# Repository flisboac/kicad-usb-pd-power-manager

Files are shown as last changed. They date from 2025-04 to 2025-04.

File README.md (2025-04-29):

# USB-PD Power Manager

This is a USB-PD-capable Battery Charger and Power Path Module based on the [HUSB238 USB-PD Sink Controller](https://www.hynetek.com/uploadfiles/site/219/news/aabbbbdb-48c9-4a44-a6dc-2c15f53282e6.pdf) and [BQ25672 Battery Charger](https://www.ti.com/lit/ds/symlink/bq25672.pdf).

> This is **NOT** a finished project!

## Objectives

The main objective with this module is, quite literally, to make the "perfect Power Manager module/solution for any project." Obviously, "perfect" here is what I consider perfect myself, so here goes a laundry list of things I want from it:

1. Actually negotiate power when powered through USB, whatever the means.
    - A lot of projects just depend on the common 5.1K resistor on CC1/CC2 to get 5V/3A, but that's not a guarantee unless your use-case is very restricted.
    - Also, pulling 500mA or more on USB without USB connection/negotiation, USB-PD or USB-BC is out of spec. Not that it matters in all projects, but a well behaved USB-powered solution avoids many surprises.
    - 5V is pretty ubiquitous, but some projects may necessitate more voltage to drive higher-powered devices (e.g. fans), or to charge batteries more efficiently. Higher voltages are also necessary in order for USB-C to deliver more power in general.
2. Capable of negotiating power through **USB PD**, up to the highest power profile available (100W, 20V @ 5A).
    - In the future, I'd like this to be expanded to support USB-PPS as well, but chip availability is a bit low for enabling this functionality, so USB-PD will do for the moment.
3. Capable of falling back to **USB BC**, if not connecting to USB Type-C end-to-end.
    - There's plenty of power available through USB BC 1.2 or similar charger protocols, and it's still very common to use previous USB-A or USB-B (i.e. non Type-C) ports in many places.
4. Battery-powered, with a battery charger built-in.
    - Necessitates Power Path management.
    - Also necessitates battery protection measures, e.g. overcurrent protection, overvoltage protection, reverse polarity protection, etc.
5. Have the smallest possible form-factor. Be friendly to breadboarding, while still being useful as a standalone module.
    - Size would be similar to a Raspberry Pi Pico in width, but no specific restriction on length.
    - Ahem... ✨ [Castellations!](https://jlcpcb.com/blog/castellated-pcbs-introduction-and-design-requirements) ✨ (What a word, ain't it?)
6. Guaranteed 5V and 3.3V outputs, regardless of the "mains" voltage.
    - 5V with a switched dc/dc regulator, for powering sensors, LEDs, etc. Optionally adjustable to 3.3V via standalone (pin) configuration.
    - 3.3V with a LDO for powering microcontrollers, also adjustable to 5V if needed (e.g. for less noise).
    - Both can be disabled at any time, to reduce power consumption.
7. Optional external power input, as a backup for USB power.
8. Battery fuel gauge built-in to the module.
    - Helps with power consumption prediction, etc.
9. I2C as the main control option, but standalone pin or jumper based configuration also possible.
    - Standalone controls enable the board to be used in scenarios without a microcontroller.
    - I2C enables the board to be used with higher precision (e.g. negotiate USB-PD power after first negotiation, configure current/charger limits past the default standalone ones, monitor power consumption, etc.)

I also wanted to put a soft-reset button. I like the idea of the module having power and reset buttons that are useable to a microcontroller, with e.g. long presses meaning turn-off/reset, etc. Perhaps that may be included in a future revision.

## Implementation

### Component selection

Focus on ICs from known brands. Easier to predict availability and quality.

Basic test: go to JLCPCB and see if there's a good amount of stock available. Discard any option with zero stock. Price also important, but not essential (as this will be a personal project).

- USB-PD Sink Controller (**VUSB**): [**HUSB238_002DD**](https://www.hynetek.com/uploadfiles/site/219/news/aabbbbdb-48c9-4a44-a6dc-2c15f53282e6.pdf)
    - 001DD or 004DD would be the best option, but the 002DD has a whole lot more availability for some reason.
    - VUSB is not supposed to be consumed directly, but instead it must be passed on to the Power Path controller.
    - VUSB is only switched on when USB-PD negotiation is performed (either with success or failure).
- Battery Charger and Power Path (**VSYS**): [**BQ25672**](https://www.ti.com/lit/ds/symlink/bq25672.pdf)
    - Selected mostly because of the 24V input voltage tolerance.
    - Having I2C is also important, but not essential.
    - Could be the BQ25792 as well, it's pin-compatible and offers more power, but the BQ25672 has better availability
- Switch-mode DC/DC converter (**VSW**): [**TPS63070**](https://www.ti.com/lit/ds/symlink/tps63070.pdf)
    - Being able to step-up is important for scenarios with 1-cell batteries, or when the input voltage is lower than the output voltage in general. Even more important is to be able to step-down the voltage, considering the upwards of 24V inputs. Hence, it must be a buck-boost.
    - Input comes from VSYS (BQ25672), which reduces the required VIN to 19V.
    - Unfortunately, it has a 16V input voltage limit, but it's the highest limit amongst the moderately available buck-boosts out there. I found no other buck-boost as available or as cheap as this one. If anyone knows of a better option PLEASE let me know, I researched quite a lot but couldn't find a better one!
    - Because of the low VIN input, the module can only be used with up to 3-cell configurations, which limits VSYS to around 13V max. Going above that risks damaging the buck-boost.
- Low-dropout voltage regulator (**VLDO**): [**TPS7A2601**](https://www.ti.com/lit/ds/symlink/tps7a26.pdf)
    - I quite like this LDO!
    - Current limit is a bit low at 500mA, but it's enough for most projects. Higher power can be better served by VBUS or VSW
    - Target output voltages: 3.3V and 5V.
    - Has a very high VIN, at 20V. Safe to connect to VBUS/VSYS, but not exactly safe to use at higher voltages (e.g. regulate from 20V VIN but with much lower output currents in order not to blow it up!)
- MOSFETs: focus on using dual mosfet ICs, in order to reduce board space usage whenever possible.
    - Dual N-Channel: [**Si7224DN**](https://www.mouser.com/datasheet/2/427/si7224dn-1764912.pdf)
        - One of the channels has a lower Vgs, kinda weird. Could have chosen a better one.
    - Dual P-Channel: [**Si7223DN**](https://www.vishay.com/docs/75609/si7223dn.pdf)
    - N-channel and P-channel: [**DMC3025LDV**](https://www.diodes.com/datasheet/download/DMC3025LDV.pdf)
    - Focus on packages compatible with DFN-3x3. Small enough for higher power, whilst being easier to find replacements later on (e.g. chinese options like the HSBB3313, HSBB3909, HSBB6254, HSBB3202, etc.)
    - There were probably better options out there, but I got tired of looking at some point...
- Battery fuel gauge: [**MAX17205G**](https://www.analog.com/media/en/technical-documentation/data-sheets/max17201-max17215.pdf)
    - No particular reason for choosing this one other than the fact that it supports at least 3-cell batteries.
    - Has good performance, low power consumption and enough availability.
    - Useful that it can balance cells as well!

### Module topology

The KiCad schematic focuses on showing the whole module as a single page. I like the idea of being able to see the whole circuit at a glance, obviously separated by smaller logical parts, but this may not be optimal in order to show the constituent parts of the schematic as a whole.

So, follows below a diagram making more evident the constituent parts of the module, I hope it makes sense:

Topology

### Schematics

Schematics

[Schematics PDF here.](/docs/kicad/schematics/toy-usb-pd-power-manager.pdf)

### PCB layout

I stopped working on the PCB layout in order to re-evaluate the project and make a review in general, but all the constituent parts are laid out and routed (with some exceptions). For example, the switch-mode DC/DC converters are laid out according to datasheet suggestions, but are not connected to the overall board.

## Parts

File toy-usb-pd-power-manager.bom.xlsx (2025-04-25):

Id | Designator | Footprint | Order Quantity | Manufacturer Part Number | Supplier and ref
1 | Q11,Q10,Q8 | SOT-23 | 3 | AO3400A
2 | C28,C27,C25,C24,C23,C21,C19,C18,C17,C16,C15,C9 | C_0805_2012Metric | 12 | 22uF 35V
3 | C30,C26,C31,C22,C20,C11,C7,C6,C5 | C_0402_1005Metric | 9 | 100nF 35V
4 | C29,C8,C2 | C_0805_2012Metric | 3 | 10uF 35V
5 | C14,C13,C1 | C_0402_1005Metric | 3 | 47nF 35V
6 | C12,C10 | C_0402_1005Metric | 2 | 10pF 35V
7 | R57,R56,R50,R35 | R_0402_1005Metric | 4 | 56K Ohm
8 | R55 | R_0402_1005Metric | 1 | 51K Ohm
9 | R54 | R_0402_1005Metric | 1 | 68K Ohm
10 | R53 | R_0402_1005Metric | 1 | 1.5M Ohm
11 | R46,R29 | R_0402_1005Metric | 2 | 1.5K Ohm
12 | R45 | R_0402_1005Metric | 1 | 1K Ohm
13 | R44 | R_0402_1005Metric | 1 | 510 Ohm
14 | R43 | R_0402_1005Metric | 1 | 2.2K Ohm
15 | R42 | R_0402_1005Metric | 1 | 220K Ohm
16 | R41 | R_0402_1005Metric | 1 | 330K Ohm
17 | R40 | R_0402_1005Metric | 1 | 510K Ohm
18 | R39,R25,R23,R14,R12,R11,R10 | R_0402_1005Metric | 7 | 1M Ohm
19 | R38 | R_0402_1005Metric | 1 | 470K Ohm
20 | R28 | R_0402_1005Metric | 1 | 5.1K Ohm
21 | R27 | R_0402_1005Metric | 1 | 10K Ohm
22 | R26 | R_0402_1005Metric | 1 | 15K Ohm
23 | R24 | R_0402_1005Metric | 1 | 2M Ohm
24 | R22,R21,R20,R19 | R_0402_1005Metric | 4 | 4.7K Ohm
25 | R18,R17,R16,R15,R13,R9,R8,R7,R6 | R_0402_1005Metric | 9 | 10M Ohm
26 | R5 | R_0402_1005Metric | 1 | 100 Ohm
27 | R4 | R_0402_1005Metric | 1 | 10 Ohm
28 | R3,R2 | R_0402_1005Metric | 2 | 330 Ohm
29 | R1 | R_0402_1005Metric | 1 | 0 Ohm
30 | D15 | LED_0603_1608Metric | 1 | LED
31 | D14 | LED_0603_1608Metric | 1 | LED
32 | J4 | PinHeader_1x12_P2.54mm_Vertical | 2 | Pin Header 1x12 P2.54mm Vertical
33 | J3 | PinHeader_1x4_P2.54mm_Vertical | 1 | Pin Header 1x4 P2.54mm Vertical
34 | U4 | Texas_S-PWSON-N10_ThermalVias | 1 | TPS63060
35 | U3 | SPECIFIC_BQ25672RQMR | 1 | BQ25672
36 | U2 | SPECIFIC_TPS7A2601DRVR_NoThermalVias | 1 | TPS7A2601DRVR
37 | U1 | DFN-10-1EP_3x3mm_P0.5mm_EP1.7x2.5mm | 1 | HUSB238_002DD
39 | Q9,Q1 | Vishay_PowerPAK_1212-8_Dual | 2 | Si7223DN
40 | Q7,Q6,Q5 | SOT-363_SC-70-6 | 3 | BSS138PS
41 | Q4,Q3,Q2 | Vishay_PowerPAK_1212-8_Dual | 3 | Si7224DN
42 | L2,L1 | L_6.3x6.3_H3 | 2 | 1uH 8A
44 | D13,D12,D2,D1 | D_SOD-323 | 4 | 1N5819WS
45 | D11,D5,D4 | D_SMF | 3 | SMF24A
46 | D10 | D_SMA | 1 | 1SMA4747A
47 | D9,D6 | SOT-23-6 | 2 | SMF05CT1G
48 | D8,D7 | D_SMA | 2 | 1SMA4745A
49 | D3 | D_SOD-123F | 1 | SMF16CA
50 | C4,C3 | C_0805_2012Metric | 2 | 2.2uF 35V
52 | J1 | USB_C_Receptacle_GCT_USB4105-xx-A_16P_TopMnt_Horizontal | 1 | USB-C Receptacle GCT USB4105-xx-A 16P Top Mount Horizontal

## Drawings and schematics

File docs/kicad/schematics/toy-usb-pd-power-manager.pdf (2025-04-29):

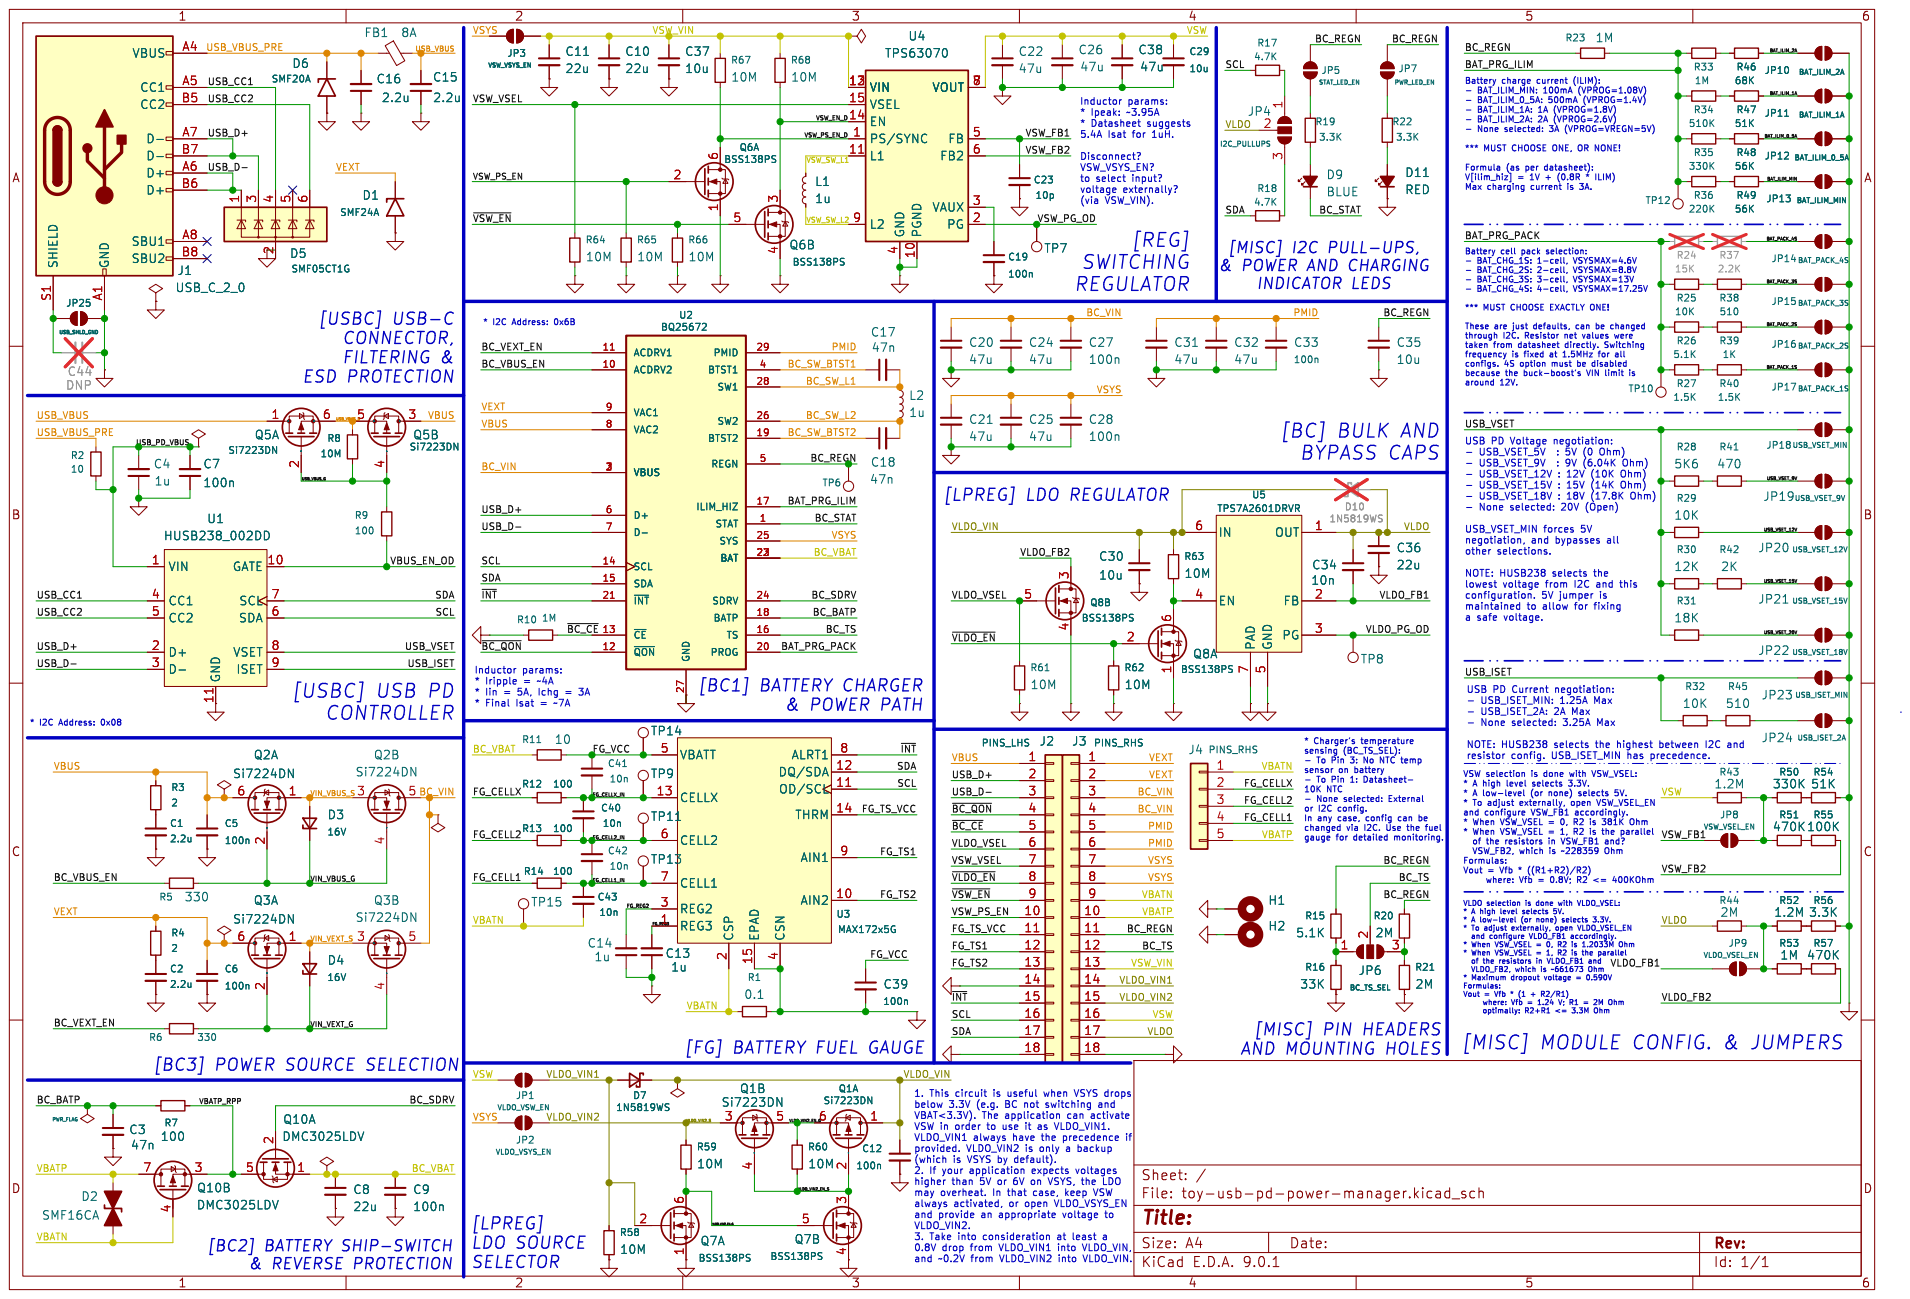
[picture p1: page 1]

6 1 U4 TPS63070 VIN 123 VSEL 15 EN 14 PS/SYNC 1

4 PGND 10 VOUT 78 FB 5 FB2 6 VAUX 3 PG 2 U4 TPS63070

4 PGND 10 VOUT 78 FB 5 FB2 6 VAUX 3 PG 2 C29
I2C_PULLUPS VIN 123 VSEL 15 EN 14 PS/SYNC 1

to select input voltage externally
(via VSW_VIN).
[REG]

a safe voltage. [LPREG] LDO REGULATOR

4 ALRT1 8 DQ/SDA 12 OD/SCL 11 THRM 14 AIN1 9 AIN2 10U3MAX172x5G H1 VIN 1 CC1 4 CC2 5 D+ 2 D- 3 GND 11 GATE 10 SCL 7 SDA 6 VSET 8

lowest voltage from I2C and this

VSW_FB1 USB_ISET
USB PD Current negotiation: - USB_ISET_MIN: 1.25A Max

4 ALRT1 8 DQ/SDA 12 OD/SCL 11 THRM 14 AIN1 9 AIN2 10

sensing (BC_TS_SEL): - To Pin 3: No NTC temp

sensor on battery
- To Pin 1: Datasheet- 10K NTC

[MISC] MODULE CONFIG. & JUMPERS

[FG] BATTERY FUEL GAUGE

Id: 1/1 Title: File: toy-usb-pd-power-manager.kicad_sch Sheet: /

0.8V drop from VLDO_VIN1 into VLDO_VIN, and ~0.2V from VLDO_VIN2 into VLDO_VIN. [LPREG]

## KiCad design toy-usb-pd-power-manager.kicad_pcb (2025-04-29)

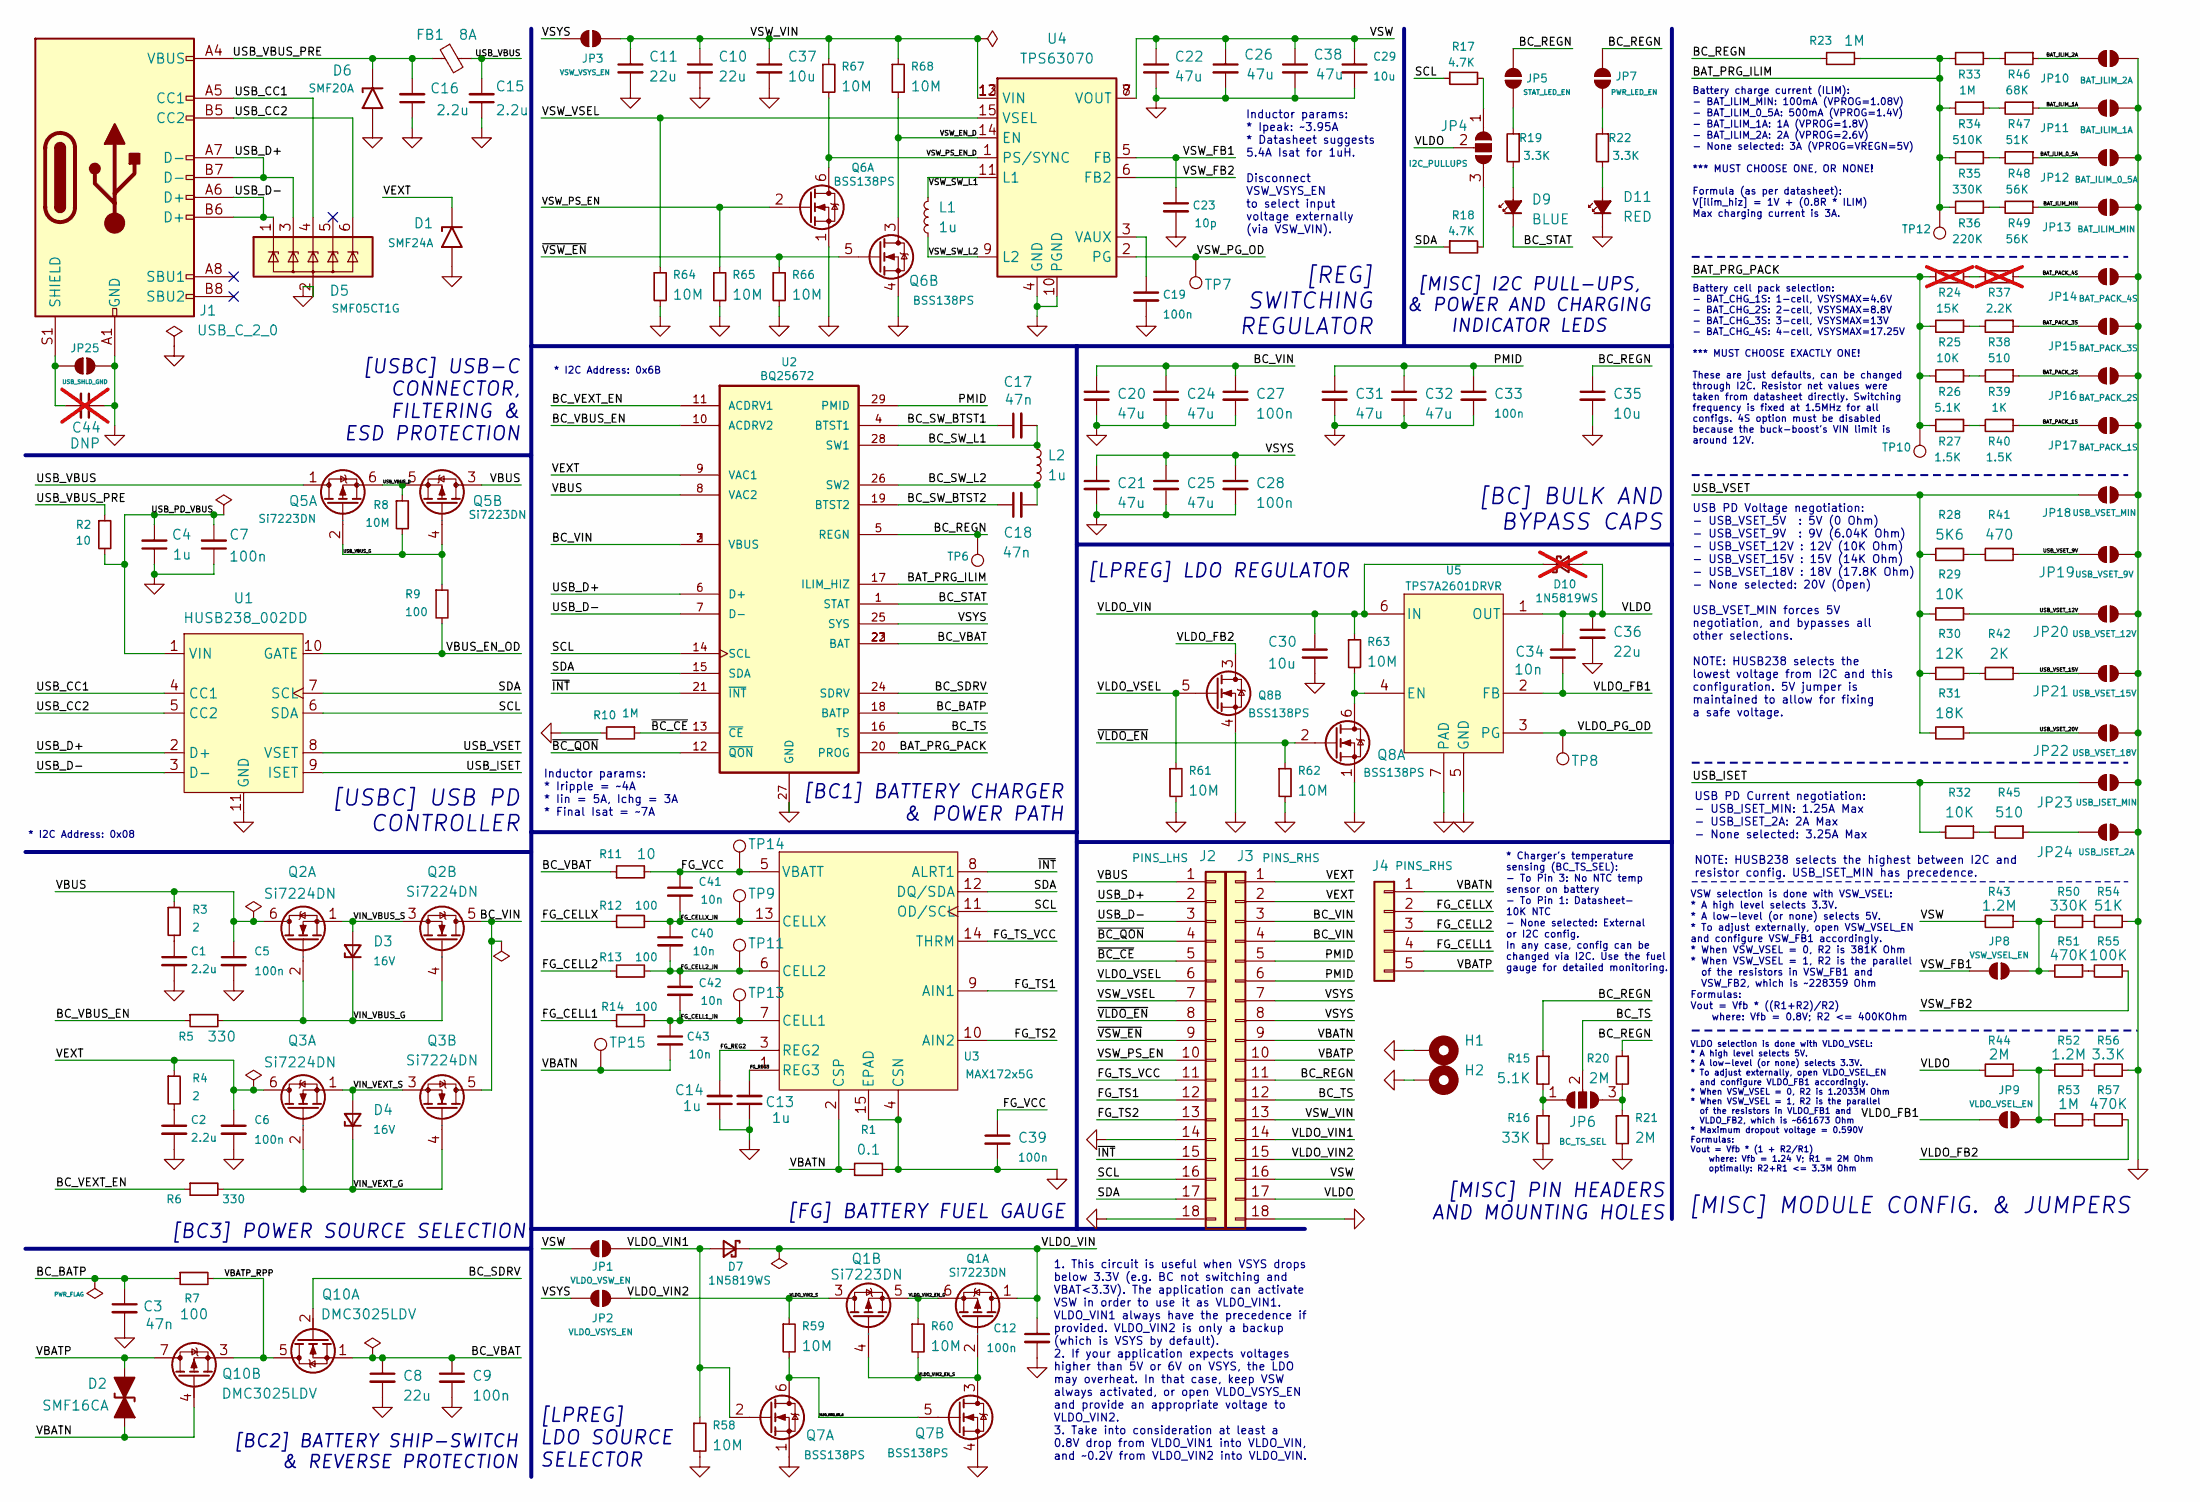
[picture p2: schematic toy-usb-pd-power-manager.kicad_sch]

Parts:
C1, C2: 2.2u; C_0805_2012Metric
C3, C17, C18: 47n; C_0402_1005Metric
C4, C13, C14: 1u; C_0402_1005Metric
C5, C6, C7, C9, C12, C19, C27, C28, C33, C39: 100n; C_0402_1005Metric
C8, C10, C11, C36: 22u; C_0805_2012Metric
C15, C16: 2.2u; C_0603_1608Metric
C20, C21, C22, C24, C25, C26, C31, C32, C38: 47u; C_0805_2012Metric
C23: 10p; C_0402_1005Metric
C29, C37: 10u; C_0603_1608Metric
C30, C35: 10u; C_0805_2012Metric
C34, C40, C41, C42, C43: 10n; C_0402_1005Metric
C44: DNP; C_0603_1608Metric; not fitted
D1: SMF24A; D_SMF
D2: SMF16CA; D_SOD-123F
D3, D4: 16V; D_SOD-523
D5: SMF05CT1G; SOT-23-6
D6: SMF20A; D_SMF
D7: 1N5819WS; D_SOD-323
D9: BLUE; LED_0603_1608Metric
D10: 1N5819WS; D_SOD-323; not fitted
D11: RED; LED_0603_1608Metric
FB1: 8A; L_1210_3225Metric
H1, H2: MountingHole_Pad; MountingHole_2.2mm_M2_DIN965_Pad_TopBottom
J1: USB_C_2_0; USB_C_Receptacle_GCT_USB4105-xx-A_16P_TopMnt_Horizontal
J2: PINS_LHS; PinHeader_1x18_P2.54mm_Vertical
J3: PINS_RHS; PinHeader_1x18_P2.54mm_Vertical
J4: PINS_RHS; PinHeader_1x05_P2.54mm_Vertical
JP1: VLDO_VSW_EN; SolderJumper-2_P1.3mm_Open_Pad1.0x1.5mm
JP2: VLDO_VSYS_EN; SolderJumper-2_P1.3mm_Open_Pad1.0x1.5mm
JP3: VSW_VSYS_EN; SolderJumper-2_P1.3mm_Open_Pad1.0x1.5mm
JP4: I2C_PULLUPS; SolderJumper-3_P1.3mm_Open_Pad1.0x1.5mm
JP5: STAT_LED_EN; SolderJumper-2_P1.3mm_Open_Pad1.0x1.5mm
JP6: BC_TS_SEL; SolderJumper-3_P1.3mm_Open_Pad1.0x1.5mm
JP7: PWR_LED_EN; SolderJumper-2_P1.3mm_Open_Pad1.0x1.5mm
JP8: VSW_VSEL_EN; SolderJumper-2_P1.3mm_Open_Pad1.0x1.5mm
JP9: VLDO_VSEL_EN; SolderJumper-2_P1.3mm_Open_Pad1.0x1.5mm
JP10: BAT_ILIM_2A; SolderJumper-2_P1.3mm_Open_Pad1.0x1.5mm
JP11: BAT_ILIM_1A; SolderJumper-2_P1.3mm_Open_Pad1.0x1.5mm
JP12: BAT_ILIM_0_5A; SolderJumper-2_P1.3mm_Open_Pad1.0x1.5mm
JP13: BAT_ILIM_MIN; SolderJumper-2_P1.3mm_Open_Pad1.0x1.5mm
JP14: BAT_PACK_4S; SolderJumper-2_P1.3mm_Open_Pad1.0x1.5mm
JP15: BAT_PACK_3S; SolderJumper-2_P1.3mm_Open_Pad1.0x1.5mm
JP16: BAT_PACK_2S; SolderJumper-2_P1.3mm_Open_Pad1.0x1.5mm
JP17: BAT_PACK_1S; SolderJumper-2_P1.3mm_Open_Pad1.0x1.5mm
JP18: USB_VSET_MIN; SolderJumper-2_P1.3mm_Open_Pad1.0x1.5mm
JP19: USB_VSET_9V; SolderJumper-2_P1.3mm_Open_Pad1.0x1.5mm
JP20: USB_VSET_12V; SolderJumper-2_P1.3mm_Open_Pad1.0x1.5mm
JP21: USB_VSET_15V; SolderJumper-2_P1.3mm_Open_Pad1.0x1.5mm
JP22: USB_VSET_18V; SolderJumper-2_P1.3mm_Open_Pad1.0x1.5mm
JP23: USB_ISET_MIN; SolderJumper-2_P1.3mm_Open_Pad1.0x1.5mm
JP24: USB_ISET_2A; SolderJumper-2_P1.3mm_Open_Pad1.0x1.5mm
JP25: USB_SHLD_GND; SolderJumper-2_P1.3mm_Open_Pad1.0x1.5mm
L1, L2: 1u; L_Changjiang_FXL0530
Q1, Q5: Si7223DN; Vishay_PowerPAK_1212-8_Dual
Q2, Q3: Si7224DN; Vishay_PowerPAK_1212-8_Dual
Q6, Q7, Q8: BSS138PS; SOT-363_SC-70-6
Q10: DMC3025LDV; Diodes_PowerDI3333-8_UXC_3.3x3.3mm_P0.65mm
R1: 0.1; R_1210_3225Metric
R2: 10; R_0402_1005Metric
R3: 2; R_0603_1608Metric
R4: 2; R_0402_1005Metric
R5, R6: 330; R_0402_1005Metric
R7, R9: 100; R_0402_1005Metric
R8, R58, R59, R60, R61, R62, R63, R64, R65, R66, R67, R68: 10M; R_0402_1005Metric
R10, R23, R33: 1M; R_0402_1005Metric
R11: 10; R_0603_1608Metric
R12, R13, R14: 100; R_0603_1608Metric
R15, R26: 5.1K; R_0402_1005Metric
R16: 33K; R_0402_1005Metric
R17, R18: 4.7K; R_0402_1005Metric
R19, R22: 3.3K; R_0402_1005Metric
R20, R21: 2M; R_0402_1005Metric
R24: 15K; R_0402_1005Metric; not fitted
R25: 10K; R_0402_1005Metric
R27, R40: 1.5K; R_0402_1005Metric
R28: 5K6; R_0402_1005Metric; LCSC C25908
R29: 10K; R_0402_1005Metric; LCSC C25744
R30: 12K; R_0402_1005Metric; LCSC C25752
R31: 18K; R_0402_1005Metric; LCSC C25762
R32: 10K; R_0402_1005Metric; LCSC C25908
R34: 510K; R_0402_1005Metric
R35: 330K; R_0402_1005Metric
R36: 220K; R_0402_1005Metric
R37: 2.2K; R_0402_1005Metric; not fitted
R38: 510; R_0402_1005Metric
R39: 1K; R_0402_1005Metric
R41: 470; R_0402_1005Metric; LCSC C25117
R42: 2K; R_0402_1005Metric; LCSC C4109
R43, R52: 1.2M; R_0402_1005Metric; LCSC C25741
R44: 2M; R_0402_1005Metric; LCSC C25741
R45: 510; R_0402_1005Metric; LCSC C25117
R46: 68K; R_0402_1005Metric
R47: 51K; R_0402_1005Metric
R48, R49: 56K; R_0402_1005Metric
R50: 330K; R_0402_1005Metric; LCSC C25741
R51, R57: 470K; R_0402_1005Metric; LCSC C25741
R53: 1M; R_0402_1005Metric; LCSC C25741
R54: 51K; R_0402_1005Metric; LCSC C25741
R55: 100K; R_0402_1005Metric; LCSC C25741
R56: 3.3K; R_0402_1005Metric; LCSC C25741
TP6, TP7, TP8, TP9, TP10, TP11, TP12, TP13, TP14, TP15: TestPoint; TestPoint_Pad_1.0x1.0mm
U1: HUSB238_002DD; DFN-10-1EP_3x3mm_P0.5mm_EP1.7x2.5mm; JLCPCB C7471904
U2: BQ25672; SPECIFIC_BQ25672RQMR; JLCPCB C3682029
U3: MAX172x5G; SPECIFIC_MAX172x5G_21-0137_T1433-2C_MXM
U4: TPS63070; SPECIFIC_TPS63070_RNM0015A
U5: TPS7A2601DRVR; SPECIFIC_TPS7A2601DRVR_NoThermalVias

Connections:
/BAT_ILIM_0_5A: JP12.1 (A), R48.1
/BAT_ILIM_1A: JP11.1 (A), R47.1
/BAT_ILIM_2A: JP10.1 (A), R46.1
/BAT_ILIM_MIN: JP13.1 (A), R49.1
/BAT_PACK_1S: JP17.1 (A), R40.1
/BAT_PACK_2S: JP16.1 (A), R39.1
/BAT_PACK_3S: JP15.1 (A), R38.1
/BAT_PACK_4S: JP14.1 (A), R37.1
/BAT_PRG_ILIM: R23.1, R33.2, R34.2, R35.2, R36.2, TP12.1, U2.17 (ILIM_HIZ)
/BAT_PRG_PACK: R24.2, R25.2, R26.2, R27.2, TP10.1, U2.20 (PROG)
/BC_BATP: C3.1, R7.1, U2.18 (BATP)
/BC_REGN: C35.1, J3.11, JP5.2 (B), JP7.2 (B), R15.1, R20.1, R23.2, TP6.1, U2.5 (REGN)
/BC_SDRV: Q10.2 (G), U2.24 (SDRV)
/BC_STAT: D9.1 (K), U2.1 (STAT)
/BC_SW_BTST1: C17.1, U2.4 (BTST1)
/BC_SW_BTST2: C18.1, U2.19 (BTST2)
/BC_SW_L1: C17.2, L2.1, U2.28 (SW1)
/BC_SW_L2: C18.2, L2.2, U2.26 (SW2)
/BC_TS: J3.12, JP6.2 (C), U2.16 (TS)
/BC_VBAT: C8.1, C9.1, Q10.1 (S), R11.1, U2.22 (BAT), U2.23 (BAT)
/BC_VBUS_EN: R5.1, U2.10 (ACDRV2)
/BC_VEXT_EN: R6.1, U2.11 (ACDRV1)
/BC_VIN: C20.1, C24.1, C27.1, J3.3, J3.4, Q2.5 (D), Q3.5 (D), U2.2 (VBUS), U2.3 (VBUS)
/FG_CELL1: J4.4, R14.1
/FG_CELL1_IN: C42.2, C43.1, R14.2, TP13.1, U3.7 (CELL1)
/FG_CELL2: J4.3, R13.1
/FG_CELL2_IN: C40.2, C42.1, R13.2, TP11.1, U3.6 (CELL2)
/FG_CELLX: J4.2, R12.1
/FG_CELLX_IN: C40.1, C41.2, R12.2, TP9.1, U3.13 (CELLX)
/FG_REG2: C14.2, U3.3 (REG2)
/FG_REG3: C13.2, U3.1 (REG3)
/FG_TS1: J2.12, U3.9 (AIN1)
/FG_TS2: J2.13, U3.10 (AIN2)
/FG_TS_VCC: J2.11, U3.14 (THRM)
/FG_VCC: C39.1, C41.1, R11.2, TP14.1, U3.5 (VBATT)
/PMID: C31.1, C32.1, C33.1, J3.5, J3.6, U2.29 (PMID)
/SCL: J2.16, R17.1, U1.6 (SDA), U2.14 (SCL), U3.11 (OD/SCL)
/SDA: J2.17, R18.1, U1.7 (SCL), U2.15 (SDA), U3.12 (DQ/SDA)
/USB_CC1: D5.4 (IO3), J1.A5 (CC1), U1.4 (CC1)
/USB_CC2: D5.6 (IO5), J1.B5 (CC2), U1.5 (CC2)
/USB_D+: D5.3 (IO2), J1.A7 (D-), J1.B7 (D-), J2.2, U1.2 (D+), U2.6 (D+)
/USB_D-: D5.1 (IO1), J1.A6 (D+), J1.B6 (D+), J2.3, U1.3 (D-), U2.7 (D-)
/USB_ISET: JP23.1 (A), R32.2, U1.9 (ISET)
/USB_PD_VBUS: C4.2, C7.2, R2.2, U1.1 (VIN)
/USB_VBUS: C15.2, FB1.2, Q5.1 (D)
/USB_VBUS_D: Q5.5 (S), Q5.6 (S), R8.1
/USB_VBUS_G: Q5.2 (G), Q5.4 (G), R8.2, R9.1
/USB_VBUS_PRE: C16.2, D6.1 (A1), FB1.1, J1.A4 (VBUS), J1.A9 (VBUS), J1.B4 (VBUS), J1.B9 (VBUS), R2.1
/USB_VSET: JP18.1 (A), R28.2, R29.2, R30.2, R31.2, U1.8 (VSET)
/USB_VSET_9V: JP19.1 (A), R41.1
/USB_VSET_12V: JP20.1 (A), R29.1
/USB_VSET_15V: JP21.1 (A), R42.1
/USB_VSET_20V: JP22.1 (A), R31.1
/VBATN: C43.2, D2.1 (A1), J3.9, J4.1, Q10.4 (G), R1.1, TP15.1, U3.2 (CSP)
/VBATP: D2.2 (A2), J3.10, J4.5, Q10.7 (D)
/VBATP_RPP: Q10.3 (S), Q10.5 (D), R7.2
/VBUS: C5.1, J2.1, Q2.6 (D), Q5.3 (D), R3.1, U2.8 (VAC2)
/VBUS_EN_OD: R9.2, U1.10 (GATE)
/VEXT: C6.1, D1.1 (A1), J3.1, J3.2, Q3.6 (D), R4.1, U2.9 (VAC1)
/VIN_VBUS_G: D3.1 (K), Q2.2 (G), Q2.4 (G), R5.2
/VIN_VBUS_S: D3.2 (A), Q2.1 (S), Q2.3 (S)
/VIN_VEXT_G: D4.1 (K), Q3.2 (G), Q3.4 (G), R6.2
/VIN_VEXT_S: D4.2 (A), Q3.1 (S), Q3.3 (S)
/VLDO: C34.1, C36.1, D10.2 (A), J3.17, JP4.2 (C), R44.2, U5.1 (OUT)
/VLDO_FB1: C34.2, JP9.1 (A), U5.2 (FB)
/VLDO_FB2: Q8.3 (D), R57.1
/VLDO_PG_OD: TP8.1, U5.3 (PG)
/VLDO_VIN: C12.1, C30.1, D7.1 (K), D10.1 (K), Q1.1 (D), R63.1, U5.6 (IN)
/VLDO_VIN1: D7.2 (A), J3.14, JP1.2 (B), Q7.2 (G), R58.1
/VLDO_VIN2: J3.15, JP2.2 (B), Q1.3 (D), R59.1
/VLDO_VIN2_EN_G: Q1.5 (S), Q1.6 (S), Q7.5 (G), Q7.6 (D), R59.2, R60.1
/VLDO_VIN2_EN_S: Q1.2 (G), Q1.4 (G), Q7.3 (D), R60.2
/VLDO_VSEL: J2.6, Q8.5 (G), R61.1
/VSW: C22.1, C26.1, C29.1, C38.1, J3.16, JP1.1 (A), R43.2, U4.7 (VOUT), U4.8 (VOUT)
/VSW_EN_D: Q6.3 (D), R68.2, U4.14 (EN)
/VSW_FB1: C23.1, JP8.1 (A), U4.5 (FB)
/VSW_FB2: R55.1, U4.6 (FB2)
/VSW_PG_OD: TP7.1, U4.2 (PG)
/VSW_PS_EN: J2.10, Q6.2 (G), R65.1
/VSW_PS_EN_D: Q6.6 (D), R67.2, U4.1 (PS/SYNC)
/VSW_SW_L1: L1.2, U4.11 (L1)
/VSW_SW_L2: L1.1, U4.9 (L2)
/VSW_VIN: C10.1, C11.1, C37.1, J3.13, JP3.2 (B), R67.1, R68.1, U4.12 (VIN), U4.13 (VIN)
/VSW_VSEL: J2.7, R64.1, U4.15 (VSEL)
/VSYS: C21.1, C25.1, C28.1, J3.7, J3.8, JP2.1 (A), JP3.1 (A), U2.25 (SYS)
/~BC_CE: J2.5, R10.1, U2.13 (~CE)
/~BC_QON: J2.4, U2.12 (~QON)
/~INT: J2.15, U2.21 (~INT), U3.8 (ALRT1)
/~VLDO_EN: J2.8, Q8.2 (G), R62.1
/~VSW_EN: J2.9, Q6.5 (G), R66.1
GND: C1.2, C2.2, C3.2, C4.1, C5.2, C6.2, C7.1, C8.2, C9.2, C10.2, C11.2, C12.2, C13.1, C14.1, C15.1, C16.1, C19.2, C20.2, C21.2, C22.2, C23.2, C24.2, C25.2, C26.2, C27.2, C28.2, C29.2, C30.2, C31.2, C32.2, C33.2, C35.2, C36.2, C37.2, C38.2, C39.2, C44.1, D1.2 (A2), D5.2 (GND), D6.2 (A2), D11.1 (K), H1.1, H2.1, J1.A1 (GND), J1.A12 (GND), J1.B1 (GND), J1.B12 (GND), J2.14, J2.18, J3.18, JP10.2 (B), JP11.2 (B), JP12.2 (B), JP13.2 (B), JP14.2 (B), JP15.2 (B), JP16.2 (B), JP17.2 (B), JP18.2 (B), JP19.2 (B), JP20.2 (B), JP21.2 (B), JP22.2 (B), JP23.2 (B), JP24.2 (B), JP25.2 (B), Q6.1 (S), Q6.4 (S), Q7.1 (S), Q7.4 (S), Q8.1 (S), Q8.4 (S), R1.2, R10.2, R16.2, R21.2, R54.1, R56.1, R58.2, R61.2, R62.2, R64.2, R65.2, R66.2, U1.11 (GND), U2.27 (GND), U3.4 (CSN), U3.15 (EPAD), U4.4 (GND), U4.10 (PGND), U5.5 (GND), U5.7 (PAD)
unnamed: C1.1, R3.2
unnamed: C2.1, R4.2
unnamed: D9.2 (A), R19.2
unnamed: D11.2 (A), R22.2
unnamed: C44.2, J1.S1 (SHIELD), JP25.1 (A)
unnamed: JP4.1 (A), R17.2
unnamed: JP4.3 (B), R18.2
unnamed: JP5.1 (A), R19.1
unnamed: JP6.1 (A), R15.2, R16.1
unnamed: JP6.3 (B), R20.2, R21.1
unnamed: JP7.1 (A), R22.1
unnamed: JP8.2 (B), R43.1, R50.2, R51.2
unnamed: JP9.2 (B), R44.1, R52.2, R53.2
unnamed: JP24.1 (A), R45.1
unnamed: Q8.6 (D), R63.2, U5.4 (EN)
unnamed: R24.1, R37.2
unnamed: R25.1, R38.2
unnamed: R26.1, R39.2
unnamed: R27.1, R40.2
unnamed: R28.1, R41.2
unnamed: R30.1, R42.2
unnamed: R32.1, R45.2
unnamed: R33.1, R46.2
unnamed: R34.1, R47.2
unnamed: R35.1, R48.2
unnamed: R36.1, R49.2
unnamed: R50.1, R54.2
unnamed: R51.1, R55.2
unnamed: R52.1, R56.2
unnamed: R53.1, R57.2
unnamed: C19.1, U4.3 (VAUX)

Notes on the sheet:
[BC3] POWER SOURCE SELECTION
USB PD Current negotiation: - USB_ISET_MIN: 1.25A Max - USB_ISET_2A: 2A Max - None selected: 3.25A Max NOTE: HUSB238 selects the highest between I2C and resistor config. USB_ISET_MIN has precedence.
[USBC] USB PD CONTROLLER
* I2C Address: 0x08
[BC1] BATTERY CHARGER & POWER PATH
[FG] BATTERY FUEL GAUGE
USB PD Voltage negotiation: - USB_VSET_5V : 5V (0 Ohm) - USB_VSET_9V : 9V (6.04K Ohm) - USB_VSET_12V : 12V (10K Ohm) - USB_VSET_15V : 15V (14K Ohm) - USB_VSET_18V : 18V (17.8K Ohm) - None selected: 20V (Open) USB_VSET_MIN forces 5V negotiation, and bypasses all other selections. NOTE: HUSB238 selec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
Battery cell pack selection: - BAT_CHG_1S: 1-cell, VSYSMAX=4.6V - BAT_CHG_2S: 2-cell, VSYSMAX=8.8V - BAT_CHG_3S: 3-cell, VSYSMAX=13V - BAT_CHG_4S: 4-cell, VSYSMAX=17.25V *** MUST CHOOSE EXACTLY ONE! These are just defaults, can be changed through I2C. Resistor net values were taken from datasheet d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
[BC2] BATTERY SHIP-SWITCH & REVERSE PROTECTION
[MISC] PIN HEADERS AND MOUNTING HOLES
Inductor params: * Ipeak: ~3.95A * Datasheet suggests 5.4A Isat for 1uH. Disconnect VSW_VSYS_EN to select input voltage externally (via VSW_VIN).
1. This circuit is useful when VSYS drops below 3.3V (e.g. BC not switching and VBAT<3.3V). The application can activate VSW in order to use it as VLDO_VIN1. VLDO_VIN1 always have the precedence if provided. VLDO_VIN2 is only a backup (which is VSYS by default). 2. If your application expects volta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
[LPREG] LDO REGULATOR
VLDO selection is done with VLDO_VSEL: * A high level selects 5V. * A low-level (or none) selects 3.3V. * To adjust externally, open VLDO_VSEL_EN and configure VLDO_FB1 accordingly. * When VSW_VSEL = 0, R2 is 1.2033M Ohm * When VSW_VSEL = 1, R2 is the parallel of the resistors in VLDO_FB1 and VLDO_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
[MISC] I2C PULL-UPS, & POWER AND CHARGING INDICATOR LEDS
VSW selection is done with VSW_VSEL: * A high level selects 3.3V. * A low-level (or none) selects 5V. * To adjust externally, open VSW_VSEL_EN and configure VSW_FB1 accordingly. * When VSW_VSEL = 0, R2 is 381K Ohm * When VSW_VSEL = 1, R2 is the parallel of the resistors in VSW_FB1 and VSW_FB2, whic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
* I2C Address: 0x6B
* Charger's temperature sensing (BC_TS_SEL): - To Pin 3: No NTC temp sensor on battery - To Pin 1: Datasheet- 10K NTC - None selected: External or I2C config. In any case, config can be changed via I2C. Use the fuel gauge for detailed monitoring.
Battery charge current (ILIM): - BAT_ILIM_MIN: 100mA (VPROG=1.08V) - BAT_ILIM_0_5A: 500mA (VPROG=1.4V) - BAT_ILIM_1A: 1A (VPROG=1.8V) - BAT_ILIM_2A: 2A (VPROG=2.6V) - None selected: 3A (VPROG=VREGN=5V) *** MUST CHOOSE ONE, OR NONE! Formula (as per datasheet): V[ilim_hiz] = 1V + (0.8R * ILIM) Max ch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
[MISC] MODULE CONFIG. & JUMPERS
[LPREG] LDO SOURCE SELECTOR
[BC] BULK AND BYPASS CAPS
Inductor params: * Iripple = ~4A * Iin = 5A, Ichg = 3A * Final Isat = ~7A
[USBC] USB-C CONNECTOR, FILTERING & ESD PROTECTION
[REG] SWITCHING REGULATOR

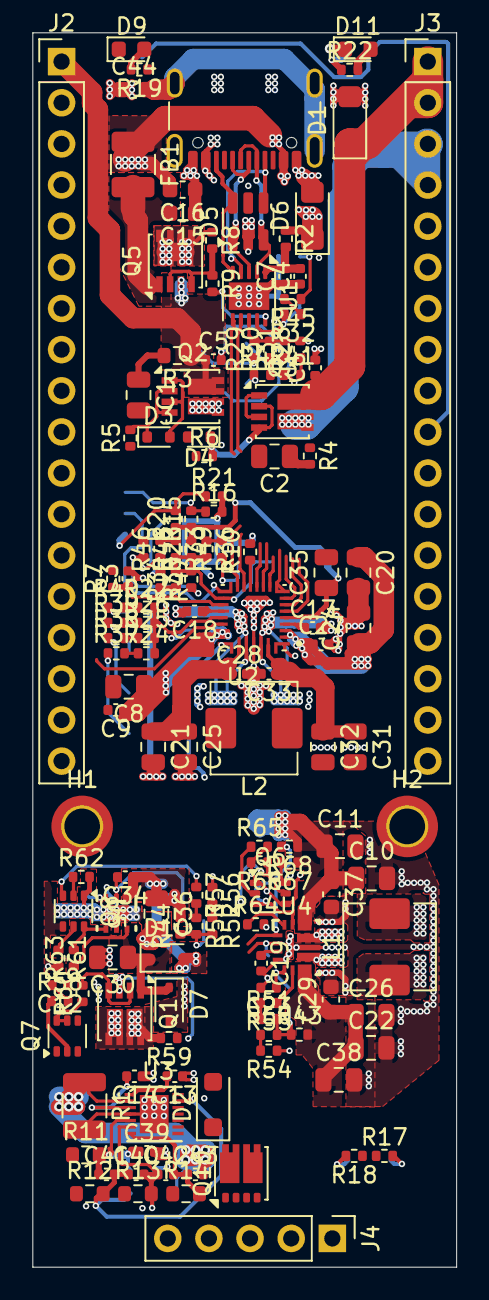
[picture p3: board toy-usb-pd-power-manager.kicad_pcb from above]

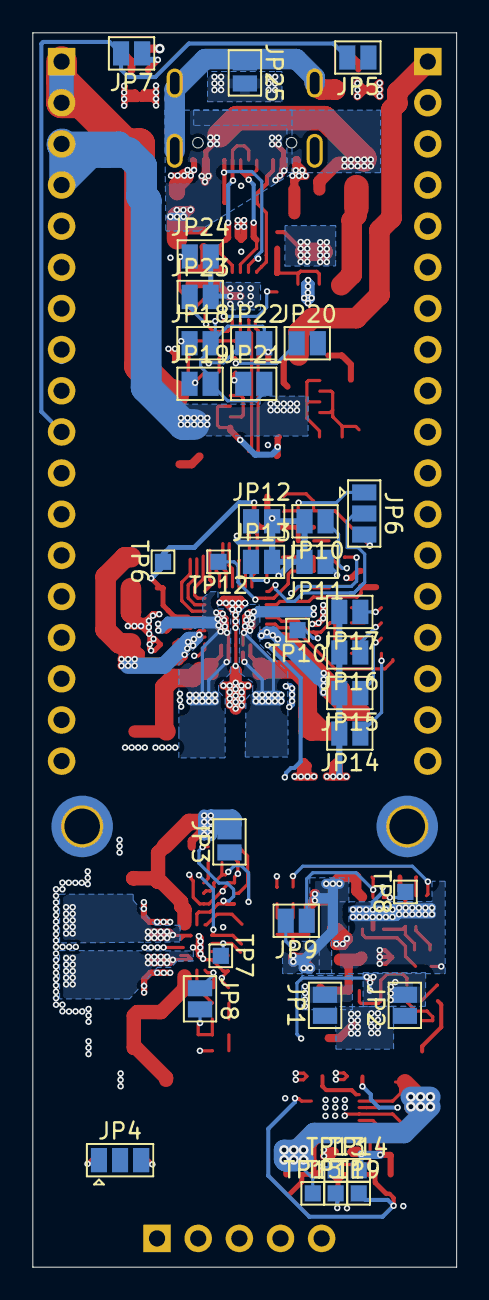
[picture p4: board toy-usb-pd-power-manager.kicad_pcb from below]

Board: 4 copper layers, 26.2 x 76.2 mm, 179 parts (35 on the bottom side), 122 nets.

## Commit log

2025-04-25 feat: initial schematic and first try on PCB
    [toy-usb-pd-power-manager.bom.csv, toy-usb-pd-power-manager.bom.xlsx, toy-usb-pd-power-manager.kicad_pcb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]
2025-04-29 refactor(pcb): improve positioning of ICs on the board
    [toy-usb-pd-power-manager.kicad_pcb, toy-usb-pd-power-manager.kicad_sch]
2025-04-29 feat: add README, diagrams and schematics
